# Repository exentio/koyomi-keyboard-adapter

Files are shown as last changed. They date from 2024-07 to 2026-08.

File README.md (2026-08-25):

# Project Koyomi - keyboard adapter boards

Adapter boards for the Vaio P keyboard, made from the reverse engineering for
Project Koyomi, read [this blog post](https://blog.exentio.sexy/2024/04/25/project-koyomi-update-2.html)
for more.  
Consider these reference designs, you can use them in hand-wired builds, to
test other keyboard variations, or for use in your own projects!  

**⚠️ WARNING: at the moment of writing, the boards haven't been tested.**  
**I'm also planning a major redesign using the RP2354B.**

The boards come in two variants, one with the RP2040 running the QMK firmware,
and another using the RP2354A with currently no firmware (waiting for QMK
support).  
For the RP2040 board, you can find the necessary build files in the
`qmk-firmware` folder. Once the board is made and tested and all the features 
are added (the extra keys are missing), it'll be pushed to the mainstream QMK
repo.  
The only supported layout for now is the JIS (Japanese) one on the first gen
Vaio P, but it's merely a matter of reversing the matrix and changing the pins
and layouts in the QMK config as necessary.  

Since the adapter's only concern is the keyboard, a header breaks out the
following:  
+ Lid detection sensor
+ Power switch
+ Power LED
+ Charging LED
+ Standby LED
+ WiFi switch
+ WiFi LED
+ Disk activity LED
+ Scroll lock LED (due to lack of GPIOs)

The keyboard connector is made by Panasonic, and the model number is
`AXK750147G`, bear in mind that the connector can connect in both ways, check
the GND connections marked on the board, the darkest traces on the keyboard
connector lead to GND.  

---

### Forking guidelines
I hope that this design will inspire people to work on similar projects, and
that they'll be used as references to learn how to work on similar projects!  
If you want to make any contribution, you're welcome to fork and send a pull
request, as long as LLMs are not directly involved and you understand your
changes: please refer to (HUMAN.md)[https://github.com/exentio/koyomi-hdmi-lvds/blob/main/HUMAN.md], thank you.  

You're also welcome to make changes to any part of this project to implement
different design choices, without having to send a pull request; however, if
your fork takes a completely different direction from Koyomi and breaks
compatibility, I kindly ask you to drop the name "Koyomi" from your project.
Please also remove every art on the PCB, if possible (wouldn't make sense to
have my face on a completely different project anyway).  
This can't and won't be enforced, so I'm just asking informally to please
respect this request, if you want to use my designs.  

### Commercial use
I purposely decided to allow commercial use for this project for two reasons: I
would be happy if modernized Vaio Ps and Koyomi were to be used in professional
contexts, and to let people distribute PCBs so everyone can build their own,
without having to sell parts myself, which is not something I can handle.  

If you plan to sell boards and parts, I only have these simple requests:  
- Please make them reasonably affordable and don't mark them up absurdly, I
want this project to be approachable from every point of view.  
- If you're profiting from reselling my designs, please donate something back
to the people who made the designs you're selling.  
- Don't remove any drawings/art on the PCBs, but you're allowed to add your own.  

None of these can and will be enforced, so I'm just asking you to respect the
time and hard work the other contributors and I have poured into designing
Koyomi.

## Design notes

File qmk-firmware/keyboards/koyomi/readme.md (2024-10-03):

# Project Koyomi keyboard adapter

Firmware used in conjunction with custom boards.  
Currently only supports the JIS layout keyboard, but porting to other layouts
should be trivial.  
Some variants may come with missing features, check the hardware info.  

* Keyboard Maintainer: [Exentio Kawasaki](https://github.com/Exentio)

Make example for this keyboard (after setting up your build environment):

    make koyomi:rp2040

Flashing example for this keyboard:

    make koyomi:rp2040:flash

See the [build environment setup](https://docs.qmk.fm/#/getting_started_build_tools) and the [make instructions](https://docs.qmk.fm/#/getting_started_make_guide) for more information. Brand new to QMK? Start with our [Complete Newbs Guide](https://docs.qmk.fm/#/newbs).

Pull down reset pin twice to enter bootloader mode. Copy the built uf2 file to the device by dragging the file to the new USB disk.

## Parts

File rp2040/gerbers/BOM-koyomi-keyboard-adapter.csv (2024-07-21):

Comment | Designator | Footprint | LCSC
15pF | C16,C17 | C_0402_1005Metric | C1548
100nF | C10,C12,C13,C15,C3,C4,C5,C6,C7,C8,C9 | C_0402_1005Metric | C1591
1uF | C1,C11,C14,C2 | C_0402_1005Metric | C1592
RP2040 | U1 | QFN-56-1EP_7x7mm_P0.4mm_EP3.2x3.2mm | C2040
ABM8-272-T3 | Y1 | Crystal_SMD_3225-4Pin_3.2x2.5mm | C20625731
27 | R5,R6 | R_0402_1005Metric | C25100
AP2112K-3.3 | U2 | SOT-23-5 | C51118
4.7K | R1,R2,R3,R4,R7 | R_0402_1005Metric | C844791
W25Q128JVS | U3 | SOIC-8_5.23x5.23mm_P1.27mm | C97521

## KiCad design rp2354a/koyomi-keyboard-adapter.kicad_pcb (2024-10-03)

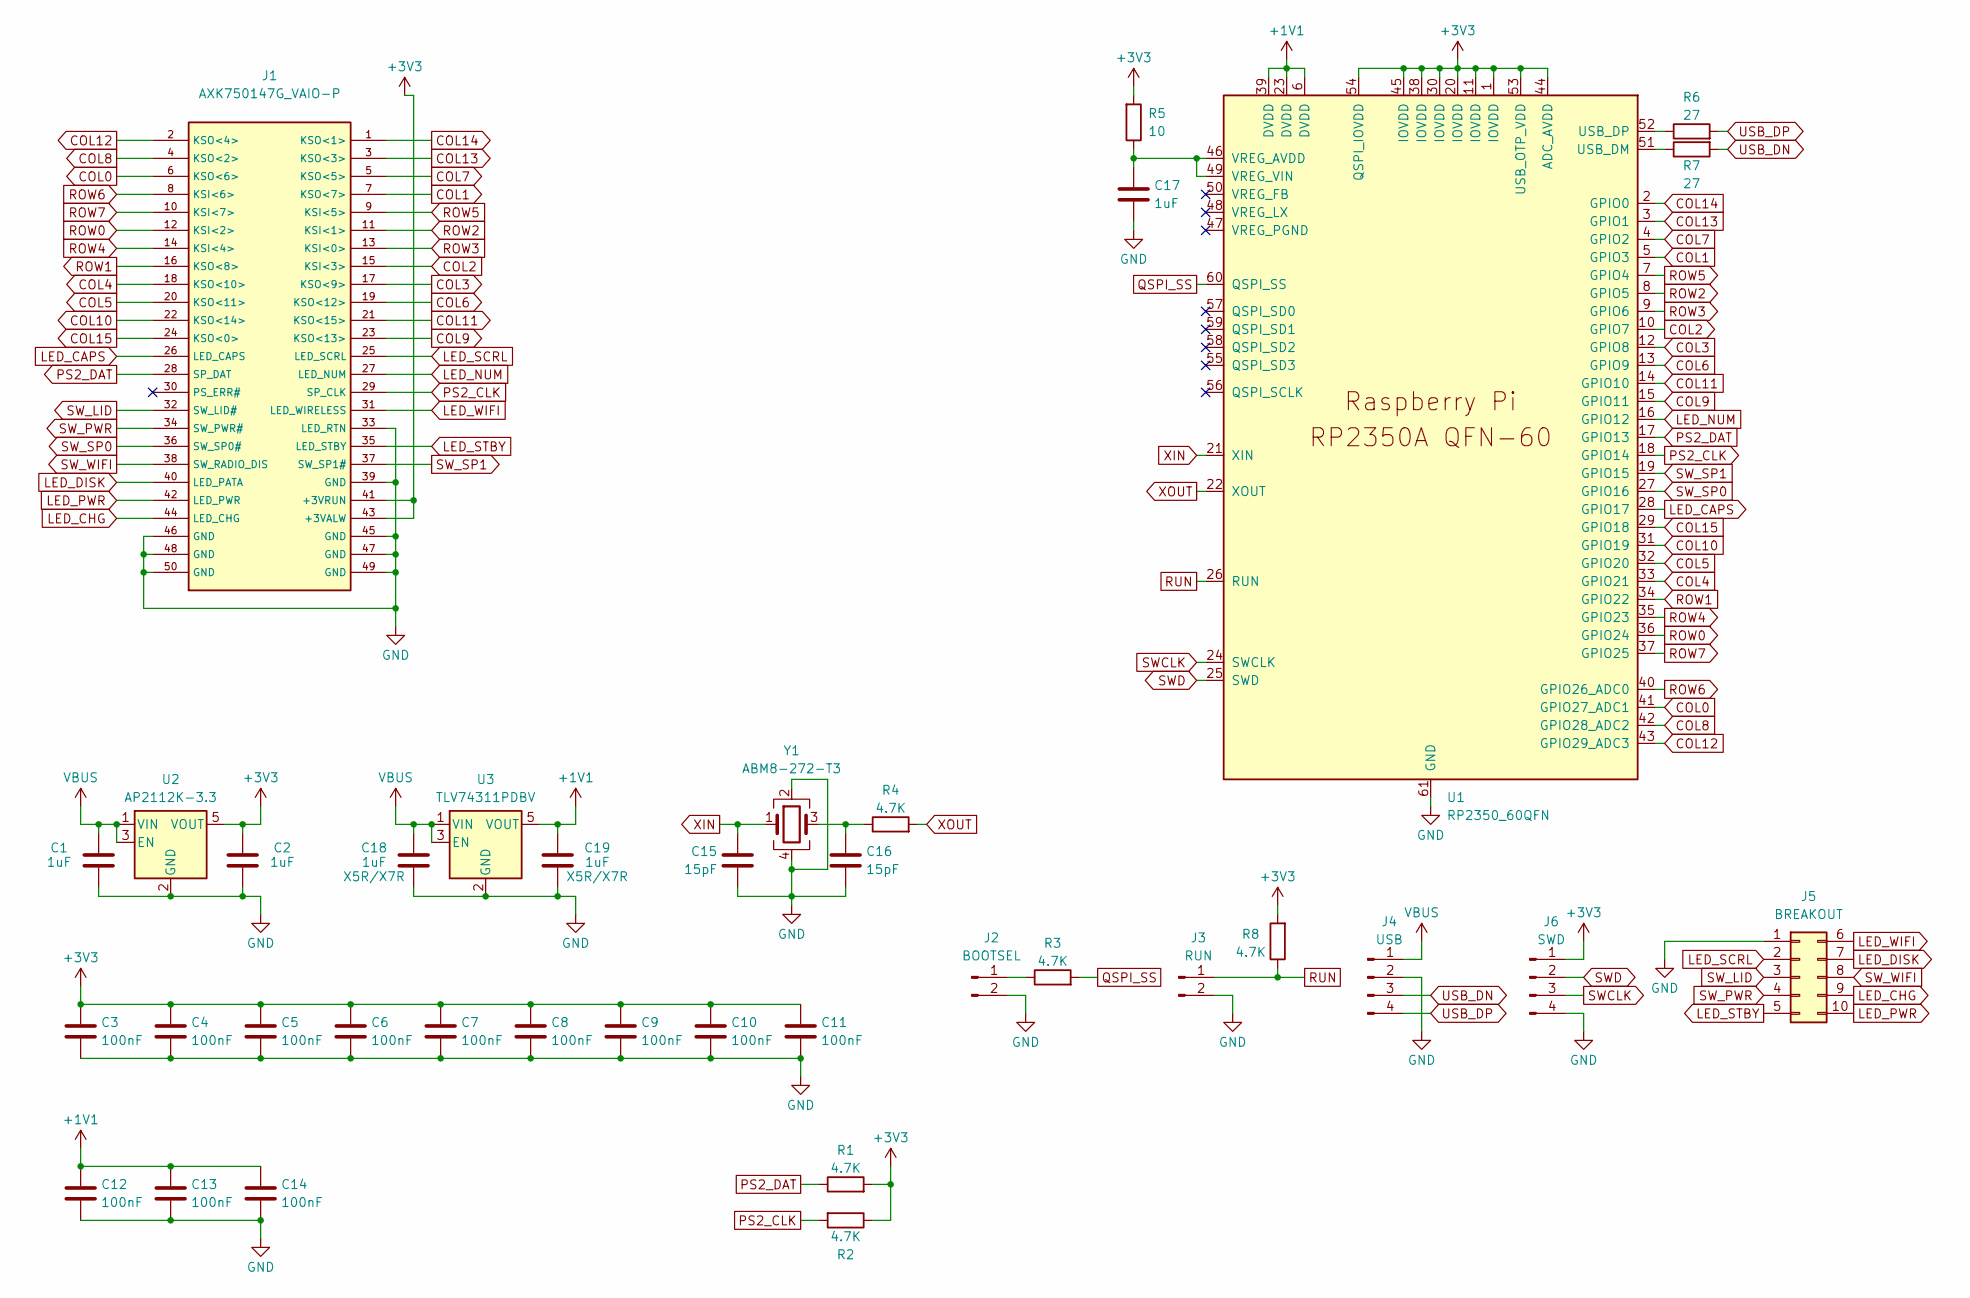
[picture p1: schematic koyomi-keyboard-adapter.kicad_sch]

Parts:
C1, C2, C17, C18, C19: 1uF; C_0402_1005Metric
C3, C4, C5, C6, C7, C8, C9, C10, C11, C12, C13, C14: 100nF; C_0402_1005Metric
C15, C16: 15pF; C_0402_1005Metric
J1: AXK750147G_VAIO-P
J2: BOOTSEL; PinHeader_1x02_P2.54mm_Vertical
J3: RUN; PinHeader_1x02_P2.54mm_Vertical
J4: USB; PinHeader_1x04_P2.54mm_Vertical
J5: BREAKOUT; PinHeader_2x05_P2.54mm_Vertical
J6: SWD; PinHeader_1x04_P2.54mm_Vertical
R1, R2, R3, R4, R8: 4.7K; R_0402_1005Metric
R5: 10; R_0402_1005Metric
R6, R7: 27; R_0402_1005Metric
U1: RP2350_60QFN; MCU_RaspberryPi_RP2350
U2: AP2112K-3.3; SOT-23-5
U3: TLV74311PDBV; SOT-23-5
Y1: ABM8-272-T3; Crystal_SMD_3225-4Pin_3.2x2.5mm

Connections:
+1V1: C12.1, C13.1, C14.1, C19.1, U1.6 (DVDD), U1.23 (DVDD), U1.39 (DVDD), U3.5 (VOUT)
+3V3: C2.1, C3.1, C4.1, C5.1, C6.1, C7.1, C8.1, C9.1, C10.1, C11.1, J1.41 (+3VRUN), J1.43 (+3VALW), J6.1, R1.2, R2.1, R5.2, R8.2, U1.1 (IOVDD), U1.11 (IOVDD), U1.20 (IOVDD), U1.30 (IOVDD), U1.38 (IOVDD), U1.44 (ADC_AVDD), U1.45 (IOVDD), U1.53 (USB_OTP_VDD), U1.54 (QSPI_IOVDD), U2.5 (VOUT); also elsewhere on the board
COL0: J1.6 (KSO<6>), U1.41 (GPIO27_ADC1)
COL1: J1.7 (KSO<7>), U1.5 (GPIO3)
COL2: J1.15 (KSI<3>), U1.10 (GPIO7)
COL3: J1.17 (KSO<9>), U1.12 (GPIO8)
COL4: J1.18 (KSO<10>), U1.33 (GPIO21)
COL5: J1.20 (KSO<11>), U1.32 (GPIO20)
COL6: J1.19 (KSO<12>), U1.13 (GPIO9)
COL7: J1.5 (KSO<5>), U1.4 (GPIO2)
COL8: J1.4 (KSO<2>), U1.42 (GPIO28_ADC2)
COL9: J1.23 (KSO<13>), U1.15 (GPIO11)
COL10: J1.22 (KSO<14>), U1.31 (GPIO19)
COL11: J1.21 (KSO<15>), U1.14 (GPIO10)
COL12: J1.2 (KSO<4>), U1.43 (GPIO29_ADC3)
COL13: J1.3 (KSO<3>), U1.3 (GPIO1)
COL14: J1.1 (KSO<1>), U1.2 (GPIO0)
COL15: J1.24 (KSO<0>), U1.29 (GPIO18)
GND: C1.2, C2.2, C3.2, C4.2, C5.2, C6.2, C7.2, C8.2, C9.2, C10.2, C11.2, C12.2, C13.2, C14.2, C15.2, C16.2, C17.2, C18.2, C19.2, J1.33 (LED_RTN), J1.39 (GND), J1.45 (GND), J1.46 (GND), J1.47 (GND), J1.48 (GND), J1.49 (GND), J1.50 (GND), J2.2, J3.2, J4.2, J5.1, J6.4, U1.61 (GND), U2.2 (GND), U3.2 (GND), Y1.2, Y1.4; also elsewhere on the board
LED_CAPS: J1.26 (LED_CAPS), U1.28 (GPIO17)
LED_CHG: J1.44 (LED_CHG), J5.9
LED_DISK: J1.40 (LED_PATA), J5.7
LED_NUM: J1.27 (LED_NUM), U1.16 (GPIO12)
LED_PWR: J1.42 (LED_PWR), J5.10
LED_SCRL: J1.25 (LED_SCRL), J5.2
LED_STBY: J1.35 (LED_STBY), J5.5
LED_WIFI: J1.31 (LED_WIRELESS), J5.6
unnamed: C16.1, R4.1, Y1.3
unnamed: J2.1, R3.1
unnamed: R7.1, U1.51 (USB_DM)
unnamed: R6.1, U1.52 (USB_DP)
unnamed: C17.1, R5.1, U1.46 (VREG_AVDD), U1.49 (VREG_VIN)
PS2_CLK: J1.29 (SP_CLK), R2.2, U1.18 (GPIO14)
PS2_DAT: J1.28 (SP_DAT), R1.1, U1.17 (GPIO13)
QSPI_SS: R3.2, U1.60 (QSPI_SS)
ROW0: J1.12 (KSI<2>), U1.36 (GPIO24)
ROW1: J1.16 (KSO<8>), U1.34 (GPIO22)
ROW2: J1.11 (KSI<1>), U1.8 (GPIO5)
ROW3: J1.13 (KSI<0>), U1.9 (GPIO6)
ROW4: J1.14 (KSI<4>), U1.35 (GPIO23)
ROW5: J1.9 (KSI<5>), U1.7 (GPIO4)
ROW6: J1.8 (KSI<6>), U1.40 (GPIO26_ADC0)
ROW7: J1.10 (KSI<7>), U1.37 (GPIO25)
RUN: J3.1, R8.1, U1.26 (RUN)
SWCLK: J6.3, U1.24 (SWCLK)
SWD: J6.2, U1.25 (SWD)
SW_LID: J1.32 (SW_LID#), J5.3
SW_PWR: J1.34 (SW_PWR#), J5.4
SW_SP0: J1.36 (SW_SP0#), U1.27 (GPIO16)
SW_SP1: J1.37 (SW_SP1#), U1.19 (GPIO15)
SW_WIFI: J1.38 (SW_RADIO_DIS), J5.8
USB_DN: J4.3, R7.2
USB_DP: J4.4, R6.2
VBUS: C1.1, C18.1, J4.1, U2.1 (VIN), U2.3 (EN), U3.1 (VIN), U3.3 (EN)
XIN: C15.1, U1.21 (XIN), Y1.1
XOUT: R4.2, U1.22 (XOUT)

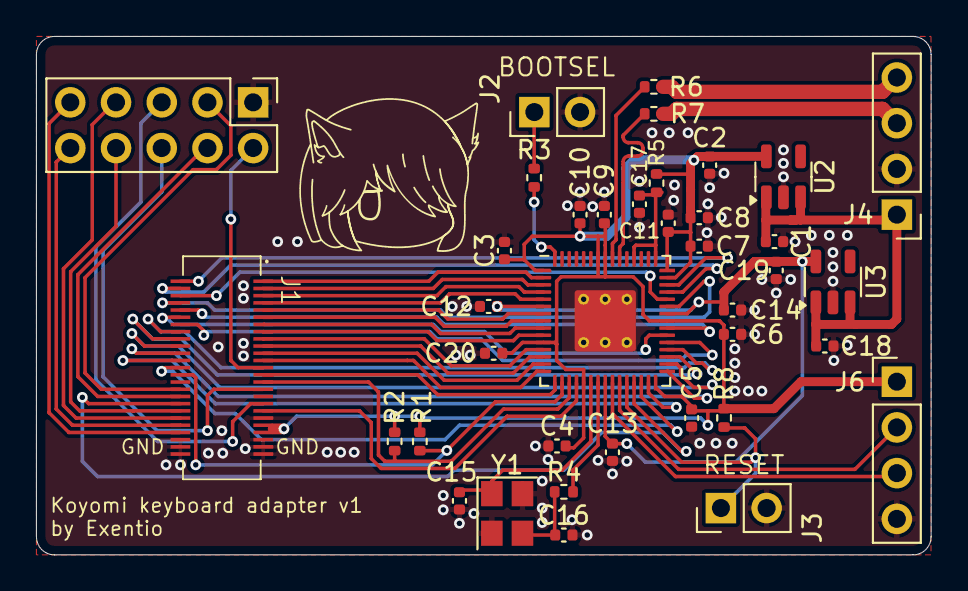
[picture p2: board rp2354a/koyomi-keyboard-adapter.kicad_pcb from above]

Board: 2 copper layers, 49.7 x 28.8 mm, 38 parts (0 on the bottom side), 56 nets.

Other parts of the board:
C20: 100nF; C_0402_1005Metric

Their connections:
+3V3: C20.1; also elsewhere on the board
GND: C20.2; also elsewhere on the board

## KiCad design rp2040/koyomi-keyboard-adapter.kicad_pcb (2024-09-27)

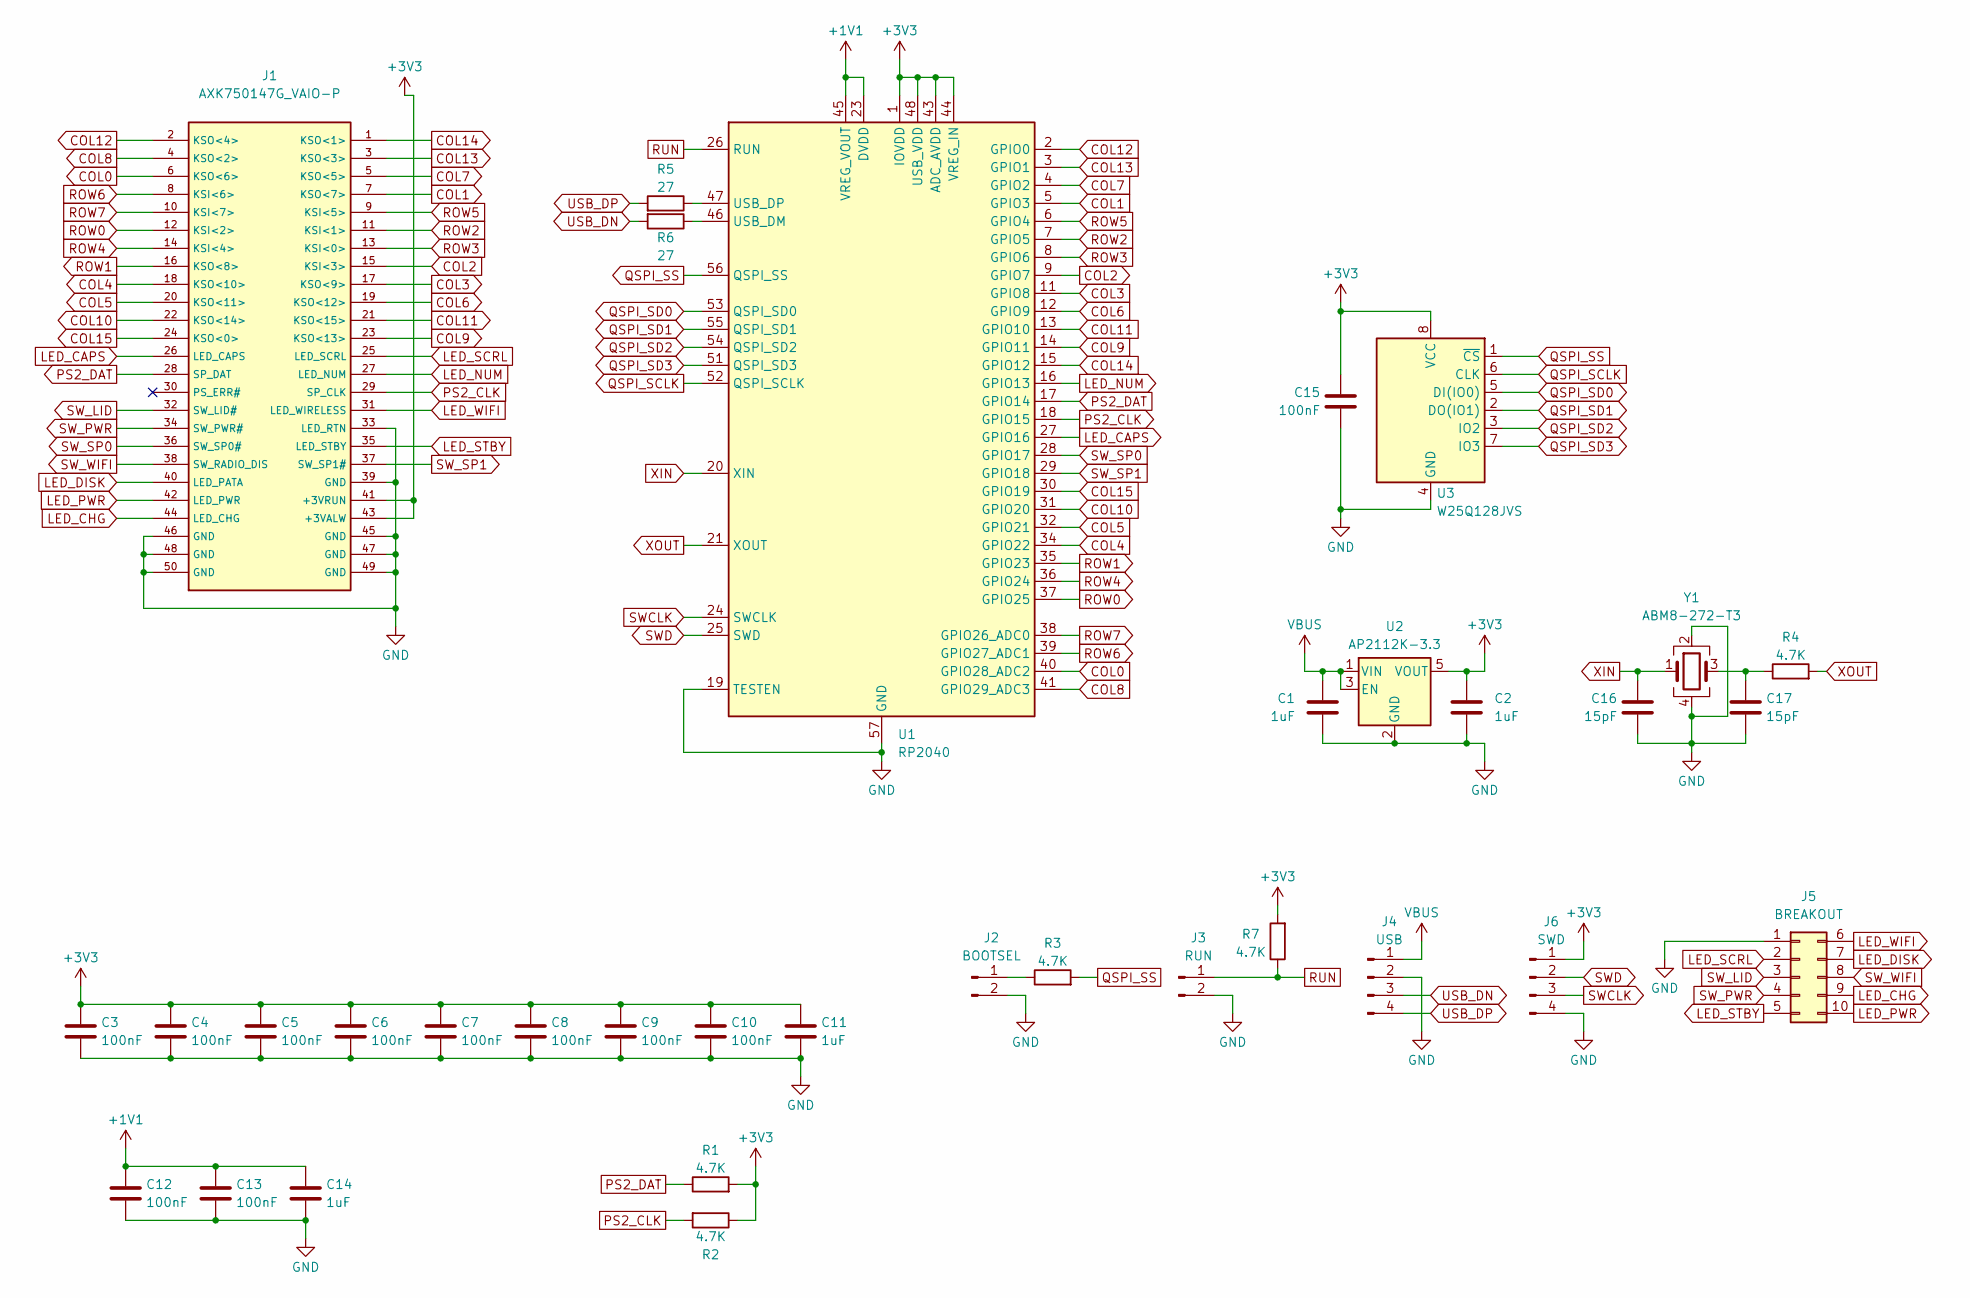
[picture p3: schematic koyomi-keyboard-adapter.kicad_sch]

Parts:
C1, C2, C11, C14: 1uF; C_0402_1005Metric
C3, C4, C5, C6, C7, C8, C9, C10, C12, C13, C15: 100nF; C_0402_1005Metric
C16, C17: 15pF; C_0402_1005Metric
J1: AXK750147G_VAIO-P
J2: BOOTSEL; PinHeader_1x02_P2.54mm_Vertical
J3: RUN; PinHeader_1x02_P2.54mm_Vertical
J4: USB; PinHeader_1x04_P2.54mm_Vertical
J5: BREAKOUT; PinHeader_2x05_P2.54mm_Vertical
J6: SWD; PinHeader_1x04_P2.54mm_Vertical
R1, R2, R3, R4, R7: 4.7K; R_0402_1005Metric
R5, R6: 27; R_0402_1005Metric
U1: RP2040; QFN-56-1EP_7x7mm_P0.4mm_EP3.2x3.2mm
U2: AP2112K-3.3; SOT-23-5
U3: W25Q128JVS; SOIC-8_5.23x5.23mm_P1.27mm
Y1: ABM8-272-T3; Crystal_SMD_3225-4Pin_3.2x2.5mm

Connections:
+1V1: C12.1, C13.1, C14.1, U1.23 (DVDD), U1.45 (VREG_VOUT), U1.50 (DVDD)
+3V3: C2.1, C3.1, C4.1, C5.1, C6.1, C7.1, C8.1, C9.1, C10.1, C11.1, C15.1, J1.41 (+3VRUN), J1.43 (+3VALW), J6.1, R1.2, R2.1, R7.2, U1.1 (IOVDD), U1.10 (IOVDD), U1.22 (IOVDD), U1.33 (IOVDD), U1.42 (IOVDD), U1.43 (ADC_AVDD), U1.44 (VREG_IN), U1.48 (USB_VDD), U1.49 (IOVDD), U2.5 (VOUT), U3.8 (VCC)
COL0: J1.6 (KSO<6>), U1.40 (GPIO28_ADC2)
COL1: J1.7 (KSO<7>), U1.5 (GPIO3)
COL2: J1.15 (KSI<3>), U1.9 (GPIO7)
COL3: J1.17 (KSO<9>), U1.11 (GPIO8)
COL4: J1.18 (KSO<10>), U1.34 (GPIO22)
COL5: J1.20 (KSO<11>), U1.32 (GPIO21)
COL6: J1.19 (KSO<12>), U1.12 (GPIO9)
COL7: J1.5 (KSO<5>), U1.4 (GPIO2)
COL8: J1.4 (KSO<2>), U1.41 (GPIO29_ADC3)
COL9: J1.23 (KSO<13>), U1.14 (GPIO11)
COL10: J1.22 (KSO<14>), U1.31 (GPIO20)
COL11: J1.21 (KSO<15>), U1.13 (GPIO10)
COL12: J1.2 (KSO<4>), U1.2 (GPIO0)
COL13: J1.3 (KSO<3>), U1.3 (GPIO1)
COL14: J1.1 (KSO<1>), U1.15 (GPIO12)
COL15: J1.24 (KSO<0>), U1.30 (GPIO19)
GND: C1.2, C2.2, C3.2, C4.2, C5.2, C6.2, C7.2, C8.2, C9.2, C10.2, C11.2, C12.2, C13.2, C14.2, C15.2, C16.2, C17.2, J1.33 (LED_RTN), J1.39 (GND), J1.45 (GND), J1.46 (GND), J1.47 (GND), J1.48 (GND), J1.49 (GND), J1.50 (GND), J2.2, J3.2, J4.2, J5.1, J6.4, U1.19 (TESTEN), U1.57 (GND), U2.2 (GND), U3.4 (GND), Y1.2, Y1.4
LED_CAPS: J1.26 (LED_CAPS), U1.27 (GPIO16)
LED_CHG: J1.44 (LED_CHG), J5.9
LED_DISK: J1.40 (LED_PATA), J5.7
LED_NUM: J1.27 (LED_NUM), U1.16 (GPIO13)
LED_PWR: J1.42 (LED_PWR), J5.10
LED_SCRL: J1.25 (LED_SCRL), J5.2
LED_STBY: J1.35 (LED_STBY), J5.5
LED_WIFI: J1.31 (LED_WIRELESS), J5.6
unnamed: C17.1, R4.1, Y1.3
unnamed: J2.1, R3.1
unnamed: R6.1, U1.46 (USB_DM)
unnamed: R5.1, U1.47 (USB_DP)
PS2_CLK: J1.29 (SP_CLK), R2.2, U1.18 (GPIO15)
PS2_DAT: J1.28 (SP_DAT), R1.1, U1.17 (GPIO14)
QSPI_SCLK: U1.52 (QSPI_SCLK), U3.6 (CLK)
QSPI_SD0: U1.53 (QSPI_SD0), U3.5 (DI(IO0))
QSPI_SD1: U1.55 (QSPI_SD1), U3.2 (DO(IO1))
QSPI_SD2: U1.54 (QSPI_SD2), U3.3 (IO2)
QSPI_SD3: U1.51 (QSPI_SD3), U3.7 (IO3)
QSPI_SS: R3.2, U1.56 (QSPI_SS), U3.1 (~CS)
ROW0: J1.12 (KSI<2>), U1.37 (GPIO25)
ROW1: J1.16 (KSO<8>), U1.35 (GPIO23)
ROW2: J1.11 (KSI<1>), U1.7 (GPIO5)
ROW3: J1.13 (KSI<0>), U1.8 (GPIO6)
ROW4: J1.14 (KSI<4>), U1.36 (GPIO24)
ROW5: J1.9 (KSI<5>), U1.6 (GPIO4)
ROW6: J1.8 (KSI<6>), U1.39 (GPIO27_ADC1)
ROW7: J1.10 (KSI<7>), U1.38 (GPIO26_ADC0)
RUN: J3.1, R7.1, U1.26 (RUN)
SWCLK: J6.3, U1.24 (SWCLK)
SWD: J6.2, U1.25 (SWD)
SW_LID: J1.32 (SW_LID#), J5.3
SW_PWR: J1.34 (SW_PWR#), J5.4
SW_SP0: J1.36 (SW_SP0#), U1.28 (GPIO17)
SW_SP1: J1.37 (SW_SP1#), U1.29 (GPIO18)
SW_WIFI: J1.38 (SW_RADIO_DIS), J5.8
USB_DN: J4.3, R6.2
USB_DP: J4.4, R5.2
VBUS: C1.1, J4.1, U2.1 (VIN), U2.3 (EN)
XIN: C16.1, U1.20 (XIN), Y1.1
XOUT: R4.2, U1.21 (XOUT)

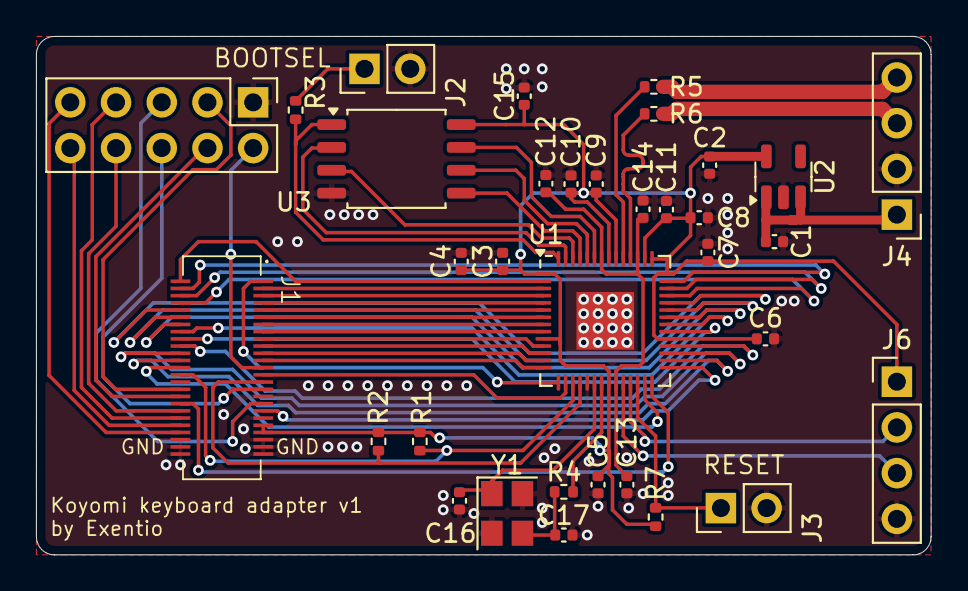
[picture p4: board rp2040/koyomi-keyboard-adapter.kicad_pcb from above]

Board: 2 copper layers, 49.7 x 28.8 mm, 34 parts (0 on the bottom side), 60 nets.

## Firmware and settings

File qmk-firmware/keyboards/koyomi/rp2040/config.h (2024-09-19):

// Copyright 2022 Stefan Kerkmann
// SPDX-License-Identifier: GPL-2.0-or-later

#pragma once

#define RP2040_BOOTLOADER_DOUBLE_TAP_RESET
#define RP2040_BOOTLOADER_DOUBLE_TAP_RESET_TIMEOUT 500U

#define PS2_DATA_PIN GP14
#define PS2_CLOCK_PIN GP15

#define LED_CAPS_LOCK_PIN GP16
#define LED_NUM_LOCK_PIN GP13
#define LED_SCROLL_LOCK_PIN GP12
#define LED_PIN_ON_STATE 1
#define MATRIX_HAS_GHOST

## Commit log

2024-07-21 Gerbers and JLCPCB files update
    [BOM-koyomi-keyboard-adapter.csv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]
2024-08-01 Changed PCB art to simple silkscreen lines
    [koyomi-keyboard-adapter.kicad_pcb]
2024-08-03 Update gerbers to reflect recent changes
    [koyomi-keyboard-adapter-B_Cu.gbl, koyomi-keyboard-adapter-B_Mask.gbs, koyomi-keyboard-adapter-B_Paste.gbp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]
2024-09-27 Decompressed matrix, broken out scroll lock LED, readme update
    [koyomi-keyboard-adapter.kicad_pcb, koyomi-keyboard-adapter.kicad_sch]
2024-10-03 RP2354A variant added, repo folder layout changed, readme update
    [BOM-koyomi-keyboard-adapter.csv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]
2024-12-27 Fix JLCPCB rotations
    [rotations.csv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]
